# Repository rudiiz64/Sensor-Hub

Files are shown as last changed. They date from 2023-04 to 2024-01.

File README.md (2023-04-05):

# Sensor-Hub

__Purpose:__ The purpose of this design is to start with an idea and see it to completion. Realistically, this sensor hub serves no real purpose, as it is mainly a way for me to begin initial schematic design and layout. This design tackles a multitude of areas that needed to be practiced, such as component selection, power distribution, and further acquiring data from datasheets.

This system utilizes an STM32L100 chip with an active reset and boot mode toggle, USB-B receptacle, onboard sensors, which include light intensity, humiditiy, and ambient temperature, an SD card, SWD breakout pins, a +5V to +3.3V linear voltage regulator, a screw terminal to fit a +5V battery with a protective eFuse, and a battery recharge circuit.

__Lessons learned:__ One of the most valuable lessons learned while progressing through this project is to fully understand what the system needs and whether or not those needs can be met. This means providing proper current, minimizing voltage drop due to trace length/width, and also understanding return current. Another notable lesson is that sometimes designs can be a little weird due to component placement. From my experience, the initial component placement will not result in the greatest system, as my original design had a voltage drop of 0.4V in the 3.3V line due to excessive trace lengths. Lastly, I learned that more time needs to be spent on designing the power side in terms of component selection AND feasibility. For instance, the design was originally only USB powered, which made no real sense as these kinds of sensors need to be flexible in terms of placement. Because of this reasoning, a battery was implemented with a battery recharge and a protective eFuse.

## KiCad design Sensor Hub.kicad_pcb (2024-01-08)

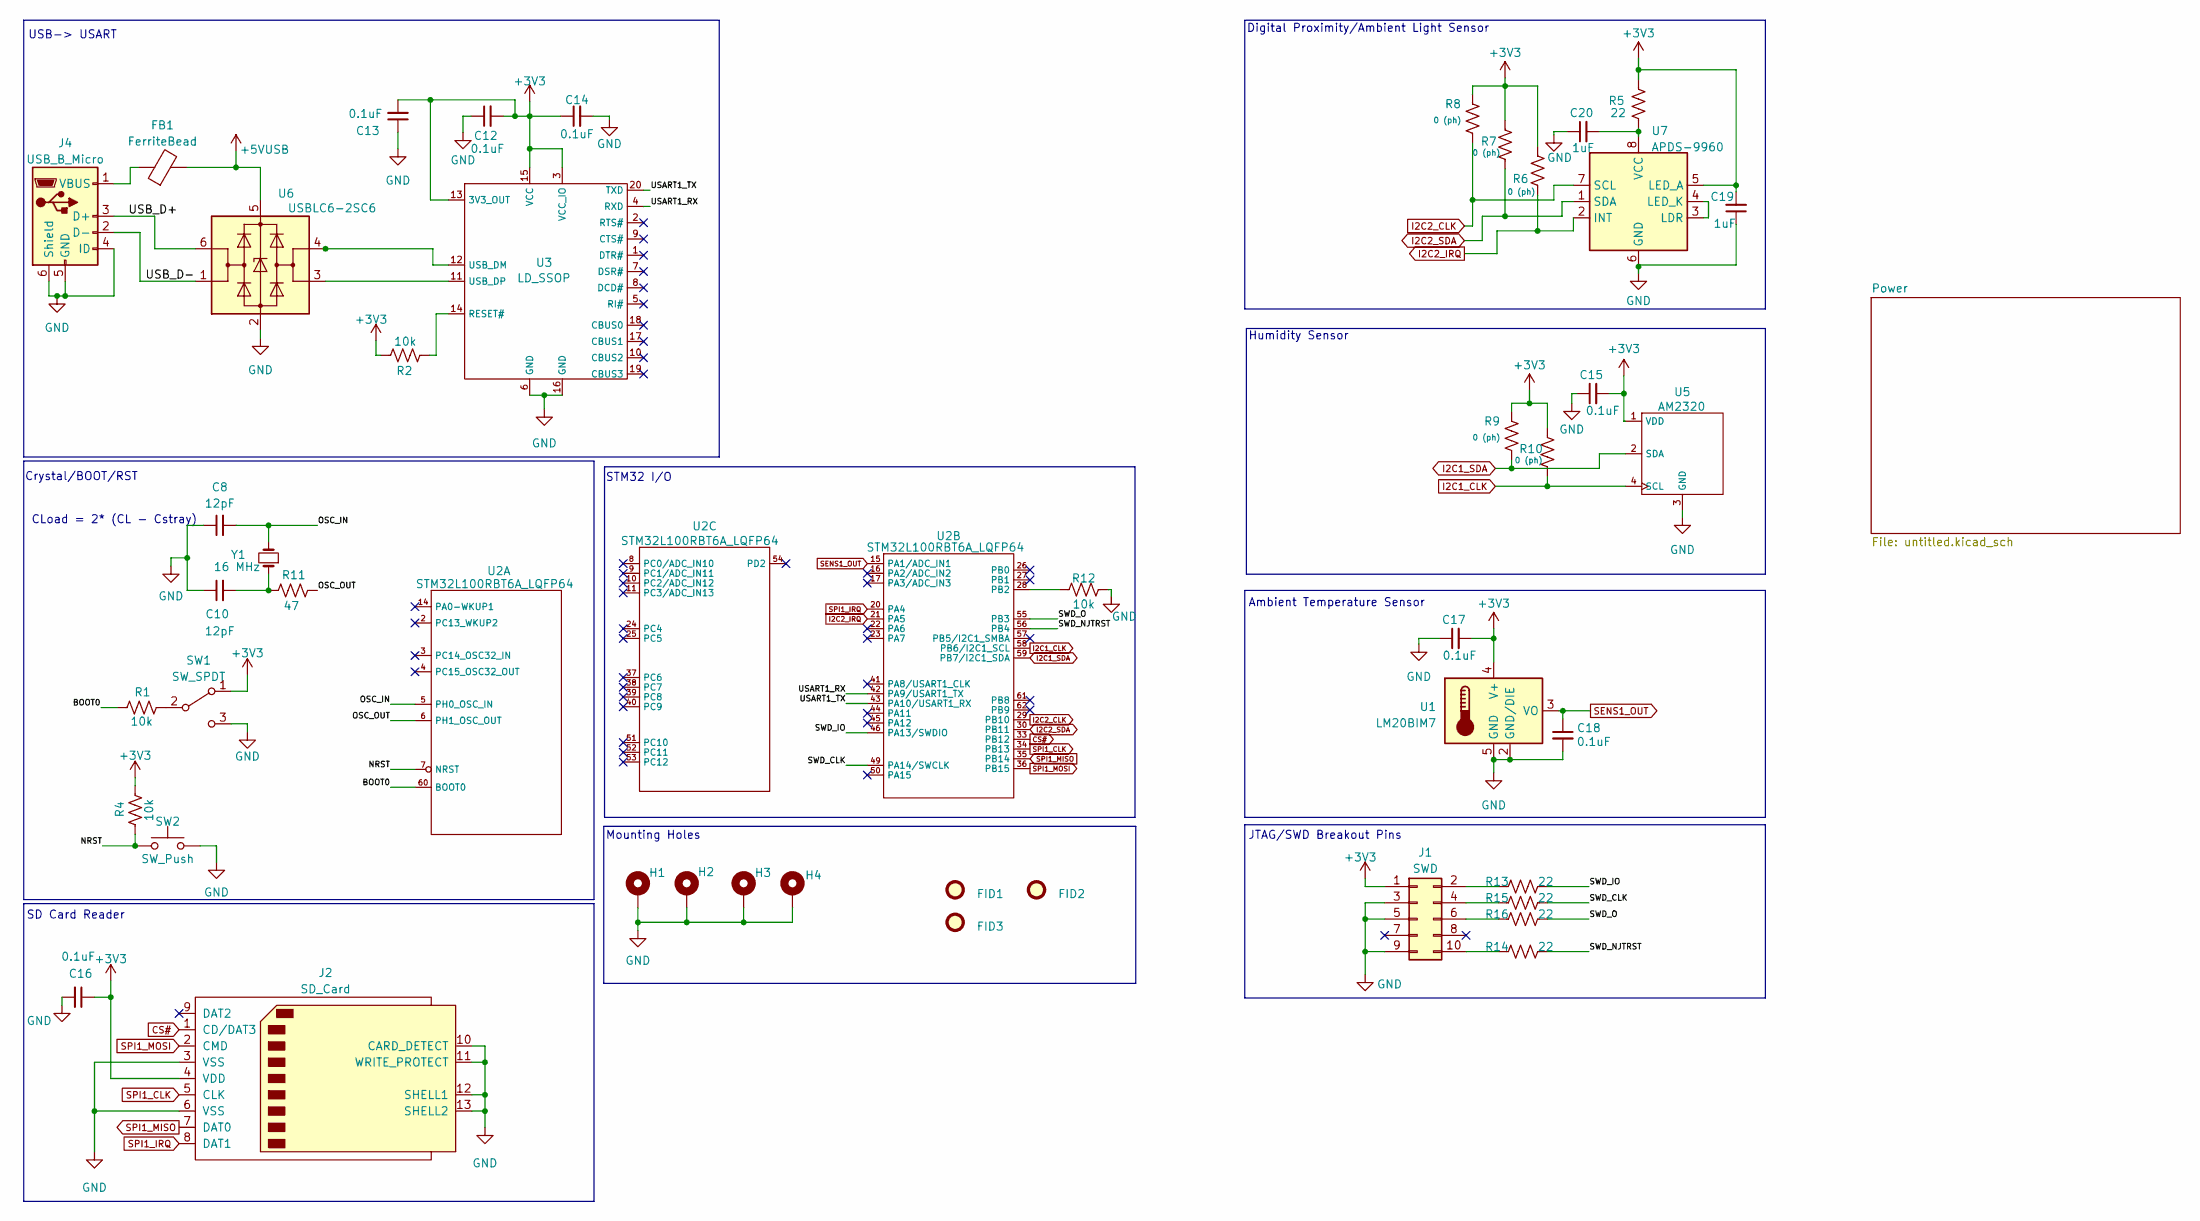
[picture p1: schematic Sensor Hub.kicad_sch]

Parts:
C8, C10: 12pF; C_0402_1005Metric
C12, C13, C14, C15, C16, C17, C18: 0.1uF; C_0603_1608Metric
C19, C20: 1uF; C_0603_1608Metric
FB1: FerriteBead; LairdTech_28C0236-0JW-10
FID1, FID2, FID3: Fiducial; Fiducial_1mm_Mask2mm
H1, H2, H3, H4: MountingHole_Pad; MountingHole_2.2mm_M2_Pad_Via
J1: SWD; PinHeader_2x05_P2.00mm_Vertical
J2: SD_Card; SD_Hirose_DM1AA_SF_PEJ82
J4: USB_B_Micro; USB_Micro-B_Amphenol_10118194_Horizontal
R1, R2, R4, R12: 10k; R_0402_1005Metric
R5, R13, R14, R15, R16: 22; R_0402_1005Metric
R6, R7, R8, R9, R10: 0 (ph); R_0402_1005Metric
R11: 47; R_0402_1005Metric
SW1: SW_SPDT; SW_E-Switch_EG1271_SPDT
SW2: SW_Push; SW_PUSH_6mm
U1: LM20BIM7; SOT-353_SC-70-5
U2: STM32L100RBT6A_LQFP64
U3: LD_SSOP; FT231_20_LD_SSOP
U5: AM2320; PinSocket_1x04_P2.00mm_Vertical
U6: USBLC6-2SC6; SOT-23-6
U7: APDS-9960; Avago_APDS-9960
Y1: 16 MHz; Crystal_SMD_0603-2Pin_6.0x3.5mm

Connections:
+3V3: C12.2, C13.2, C14.1, C15.2, C16.1, C17.2, C19.2, J1.1, J2.4 (VDD), R2.1, R4.1, R5.2, R6.2, R7.2, R8.2, R9.2, R10.2, SW1.1 (A), U1.4 (V+), U3.3 (VCC_IO), U3.13 (3V3_OUT), U3.15 (VCC), U5.1 (VDD), U7.5 (LED_A); also elsewhere on the board
+5V: FB1.2, U6.5 (VBUS); also elsewhere on the board
/BOOT0: R1.2, U2.60 (BOOT0)
/NRST: R4.2, SW2.1, U2.7 (NRST)
/OSC_IN: C8.2, U2.5 (PH0_OSC_IN), Y1.2
/OSC_OUT: R11.1, U2.6 (PH1_OSC_OUT)
/SWD_CLK: R15.2, U2.49 (PA14/SWCLK)
/SWD_IO: R13.1, U2.46 (PA13/SWDIO)
/SWD_NJTRST: R14.2, U2.56 (PB4)
/SWD_O: R16.2, U2.55 (PB3)
/USART1_RX: U2.42 (PA9/USART1_TX), U3.4 (RXD)
/USART1_TX: U2.43 (PA10/USART1_RX), U3.20 (TXD)
/USB_D+: J4.3 (D+), U6.6 (I/O1)
/USB_D-: J4.2 (D-), U6.1 (I/O1)
CS#: J2.1 (CD/DAT3), U2.33 (PB12)
GND: C8.1, C10.1, C12.1, C13.1, C14.2, C15.1, C16.2, C17.1, C18.2, C19.1, C20.1, H1.1, H2.1, H3.1, H4.1, J1.3, J1.5, J1.9, J2.3 (VSS), J2.6 (VSS), J2.10 (CARD_DETECT), J2.11 (WRITE_PROTECT), J2.12 (SHELL1), J2.13 (SHELL2), J2.CP, J2.SH, J2.SW, J2.WP, J4.4 (ID), J4.5 (GND), J4.6 (Shield), R12.2, SW1.3 (C), SW2.2, U1.2 (GND/DIE), U1.5 (GND), U3.6 (GND), U3.16 (GND), U5.3 (GND), U6.2 (GND), U7.6 (GND); also elsewhere on the board
I2C1_CLK: R10.1, U2.58 (PB6/I2C1_SCL), U5.4 (SCL)
I2C1_SDA: R9.1, U2.59 (PB7/I2C1_SDA), U5.2 (SDA)
I2C2_CLK: R8.1, U2.29 (PB10), U7.7 (SCL)
I2C2_IRQ: R6.1, U2.21 (PA5), U7.2 (INT)
I2C2_SDA: R7.1, U2.30 (PB11), U7.1 (SDA)
unnamed: C10.2, R11.2, Y1.1
unnamed: J1.2, R13.2
unnamed: J1.4, R15.1
unnamed: J1.6, R16.1
unnamed: J1.10, R14.1
unnamed: FB1.1, J4.1 (VBUS)
unnamed: R1.1, SW1.2 (B)
unnamed: R12.1, U2.28 (PB2)
unnamed: R2.2, U3.14 (RESET#)
unnamed: U3.12 (USB_DM), U6.4 (I/O2)
unnamed: U3.11 (USB_DP), U6.3 (I/O2)
unnamed: U7.3 (LDR), U7.4 (LED_K)
unnamed: C20.2, R5.1, U7.8 (VCC)
SENS1_OUT: C18.1, U1.3 (VO), U2.15 (PA1/ADC_IN1)
SPI1_CLK: J2.5 (CLK), U2.34 (PB13)
SPI1_IRQ: J2.8 (DAT1), U2.20 (PA4)
SPI1_MISO: J2.7 (DAT0), U2.35 (PB14)
SPI1_MOSI: J2.2 (CMD), U2.36 (PB15)

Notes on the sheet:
STM32 I/O
Crystal/BOOT/RST
CLoad = 2* (CL - Cstray)
Mounting Holes
Ambient Temperature Sensor
Digital Proximity/Ambient Light Sensor
JTAG/SWD Breakout Pins
SD Card Reader
Humidity Sensor
USB-> USART

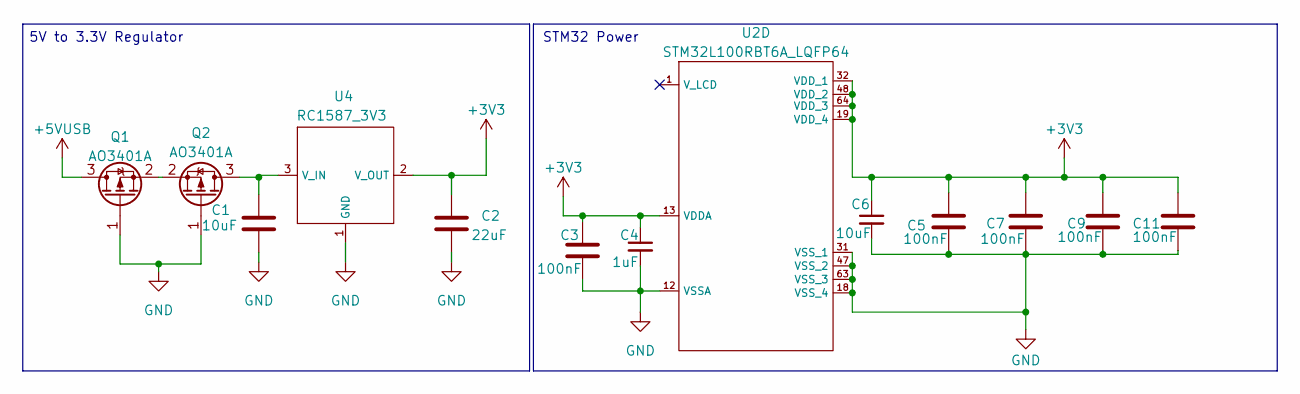
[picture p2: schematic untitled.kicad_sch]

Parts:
C1, C6: 10uF; C_0603_1608Metric
C2: 22uF; C_0603_1608Metric
C3, C5, C7, C9, C11: 100nF; C_0402_1005Metric
C4: 1uF; C_0603_1608Metric
Q1, Q2: AO3401A; SOT-23
U2: STM32L100RBT6A_LQFP64
U4: RC1587_3V3; RC1587M3V3T

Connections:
+3V3: C2.1, C3.1, C4.1, C5.1, C6.1, C7.1, C9.1, C11.1, U2.13 (VDDA), U2.19 (VDD_4), U2.32 (VDD_1), U2.48 (VDD_2), U2.64 (VDD_3), U4.2 (V_OUT); also elsewhere on the board
+5V: Q1.3 (D); also elsewhere on the board
GND: C1.2, C2.2, C3.2, C4.2, C5.2, C6.2, C7.2, C9.2, C11.2, Q1.1 (G), Q2.1 (G), U2.12 (VSSA), U2.18 (VSS_4), U2.31 (VSS_1), U2.47 (VSS_2), U2.63 (VSS_3), U4.1 (GND); also elsewhere on the board
unnamed: Q1.2 (S), Q2.2 (S)
unnamed: C1.1, Q2.3 (D), U4.3 (V_IN)

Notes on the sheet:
STM32 Power
5V to 3.3V Regulator

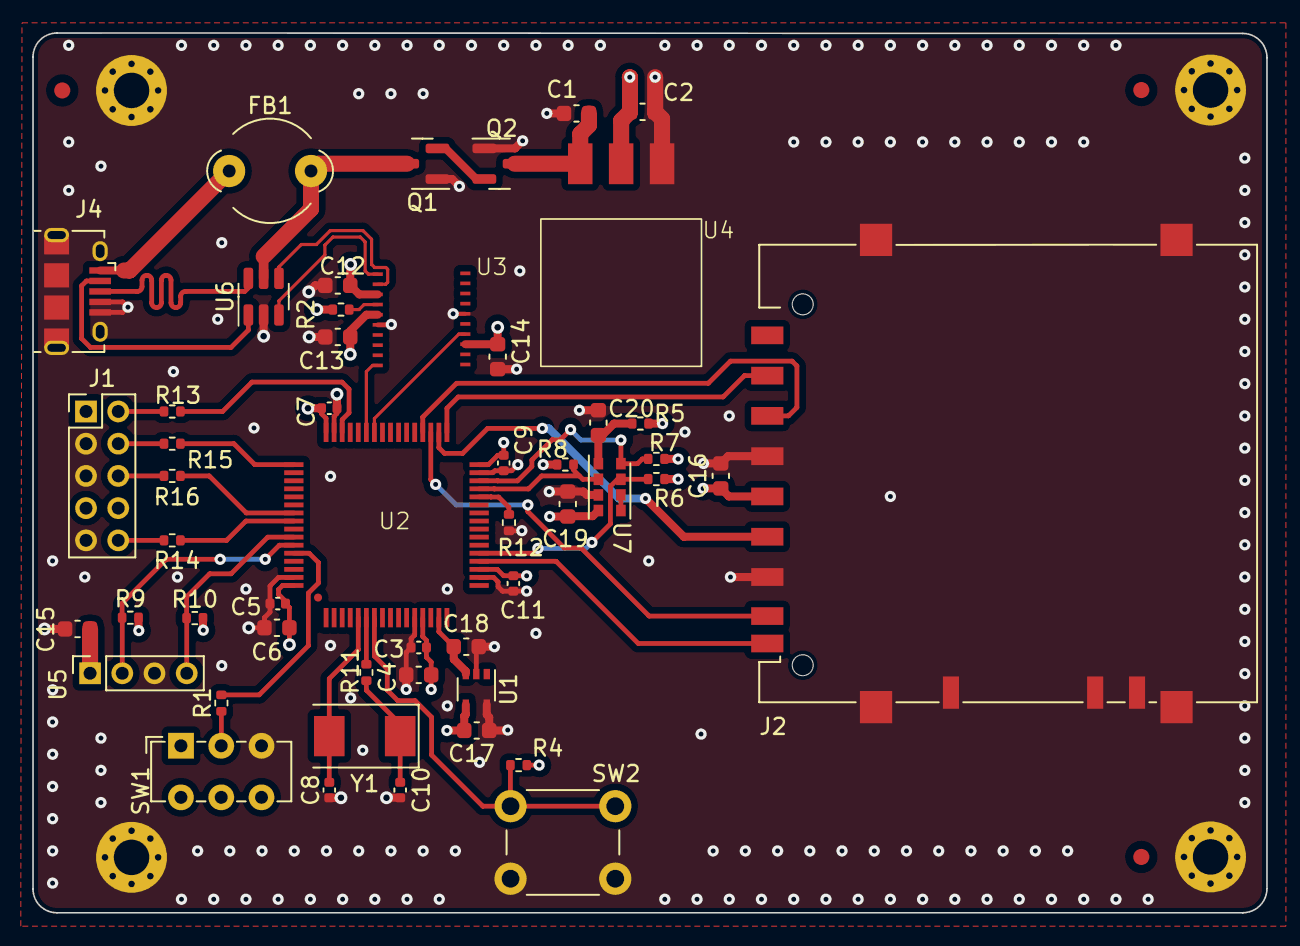
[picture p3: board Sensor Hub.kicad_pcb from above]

Board: 4 copper layers, 76.6 x 54.6 mm, 58 parts (0 on the bottom side), 41 nets.

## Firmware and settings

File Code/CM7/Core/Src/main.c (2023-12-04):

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
/* Includes ------------------------------------------------------------------*/
#include "main.h"
#include "string.h"

/* USER CODE BEGIN Includes */
#include <stdio.h>
#include "bmp180.h"
/* USER CODE END Includes */

/* USER CODE BEGIN PD */

#ifndef HSEM_ID_0
#define HSEM_ID_0 (0U) /* HW semaphore 0*/
#endif

/* USER CODE END PD */

#if defined ( __ICCARM__ ) /*!< IAR Compiler */
#pragma location=0x30000000
ETH_DMADescTypeDef  DMARxDscrTab[ETH_RX_DESC_CNT]; /* Ethernet Rx DMA Descriptors */
#pragma location=0x30000200
ETH_DMADescTypeDef  DMATxDscrTab[ETH_TX_DESC_CNT]; /* Ethernet Tx DMA Descriptors */

#elif defined ( __CC_ARM )  /* MDK ARM Compiler */

__attribute__((at(0x30000000))) ETH_DMADescTypeDef  DMARxDscrTab[ETH_RX_DESC_CNT]; /* Ethernet Rx DMA Descriptors */
__attribute__((at(0x30000200))) ETH_DMADescTypeDef  DMATxDscrTab[ETH_TX_DESC_CNT]; /* Ethernet Tx DMA Descriptors */

#elif defined ( __GNUC__ ) /* GNU Compiler */
ETH_DMADescTypeDef DMARxDscrTab[ETH_RX_DESC_CNT] __attribute__((section(".RxDecripSection"))); /* Ethernet Rx DMA Descriptors */
ETH_DMADescTypeDef DMATxDscrTab[ETH_TX_DESC_CNT] __attribute__((section(".TxDecripSection")));   /* Ethernet Tx DMA Descriptors */

#endif

ETH_TxPacketConfig TxConfig;

ETH_HandleTypeDef heth;

I2C_HandleTypeDef hi2c1;

TIM_HandleTypeDef htim16;

UART_HandleTypeDef huart3;

PCD_HandleTypeDef hpcd_USB_OTG_FS;

/* USER CODE BEGIN PV */
  //static const uint8_t BMP180_ADDRS = BMP180_ADDR << 1;

/* USER CODE END PV */

void SystemClock_Config(void);
static void MX_GPIO_Init(void);
static void MX_ETH_Init(void);
static void MX_USART3_UART_Init(void);
static void MX_USB_OTG_FS_PCD_Init(void);
static void MX_TIM16_Init(void);
static void MX_I2C1_Init(void);
/**
  * @brief  The application entry point.
  * @retval int
  */
int main(void)
{
/* USER CODE BEGIN Boot_Mode_Sequence_0 */
  int32_t timeout;
/* USER CODE END Boot_Mode_Sequence_0 */

/* USER CODE BEGIN Boot_Mode_Sequence_1 */
  /* Wait until CPU2 boots and enters in stop mode or timeout*/
  timeout = 0xFFFF;
  while((__HAL_RCC_GET_FLAG(RCC_FLAG_D2CKRDY) != RESET) && (timeout-- > 0));
  if ( timeout < 0 )
  {
  Error_Handler();
  }
/* USER CODE END Boot_Mode_Sequence_1 */
  /* MCU Configuration--------------------------------------------------------*/

  /* Reset of all peripherals, Initializes the Flash interface and the Systick. */
  HAL_Init();

  /* Configure the system clock */
  SystemClock_Config();
/* USER CODE BEGIN Boot_Mode_Sequence_2 */
/* When system initialization is finished, Cortex-M7 will release Cortex-M4 by means of
HSEM notification */
/*HW semaphore Clock enable*/
__HAL_RCC_HSEM_CLK_ENABLE();
/*Take HSEM */
HAL_HSEM_FastTake(HSEM_ID_0);
/*Release HSEM in order to notify the CPU2(CM4)*/
HAL_HSEM_Release(HSEM_ID_0,0);
/* wait until CPU2 wakes up from stop mode */
timeout = 0xFFFF;
while((__HAL_RCC_GET_FLAG(RCC_FLAG_D2CKRDY) == RESET) && (timeout-- > 0));
if ( timeout < 0 )
{
Error_Handler();
}
/* USER CODE END Boot_Mode_Sequence_2 */

  /* Initialize all configured peripherals */
  MX_GPIO_Init();
  MX_ETH_Init();
  MX_USART3_UART_Init();
  MX_USB_OTG_FS_PCD_Init();
  MX_TIM16_Init();
  MX_I2C1_Init();
  /* USER CODE BEGIN 2 */

  // Start Timer
  HAL_TIM_Base_Start_IT(&htim16);
  /* USER CODE END 2 */

  /* Infinite loop */
  /* USER CODE BEGIN WHILE */
  while (1)
  {
	  // Tell BMP180 we want to read from the temp reg
//	  buf[0] = REG_TEMP;
//	  ret = HAL_I2C_Master_Transmit(&hi2c1, BMP180_ADDR, buf, 1, HAL_MAX_DELAY);
//	  if (ret != HAL_OK){
//		  strcpy((char*) buf, "Error TX\r\n");
//	  }
//	  else {
//		  //Combine the bytes
//		  val = ((int16_t) buf[0] << 4 | buf[1] >> 4);
//	  }
//	  strcpy((char*) buf, "Hello!\r\n");
//	  HAL_UART_Transmit(&huart3, buf, strlen((char*) buf), HAL_MAX_DELAY);
//	  HAL_Delay(500);

    /* USER CODE END WHILE */

    /* USER CODE BEGIN 3 */
  }
  /* USER CODE END 3 */
}

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
/* USER CODE BEGIN 4 */
// Callback function: Timer has reset
void HAL_TIM_PeriodElapsedCallback(TIM_HandleTypeDef *htim){
	if (htim == &htim16){
		HAL_GPIO_TogglePin(LD1_GPIO_Port, LD1_Pin);
	}
}
/* USER CODE END 4 */
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


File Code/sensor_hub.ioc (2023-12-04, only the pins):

Mcu.UserName=STM32H745ZITx
PA1.Signal=ETH_REF_CLK
PA11.Signal=USB_OTG_FS_DM
PA12.Signal=USB_OTG_FS_DP
PA2.Signal=ETH_MDIO
PA7.Signal=ETH_CRS_DV
PA8.Signal=USB_OTG_FS_SOF
PA9.Signal=USB_OTG_FS_VBUS
PB0.GPIO_Label=LD1 [Green Led]
PB0.Signal=GPIO_Output
PB13.Signal=ETH_TXD1
PB14.GPIO_Label=LD3 [Red Led]
PB14.Signal=GPIO_Output
PB6.Signal=I2C1_SCL
PB7.Signal=I2C1_SDA
PC1.Signal=ETH_MDC
PC13.GPIO_Label=B1 [Blue PushButton]
PC13.Signal=GPIO_Input
PC4.Signal=ETH_RXD0
PC5.Signal=ETH_RXD1
PD10.GPIO_Label=USB_OTG_FS_PWR_EN
PD10.Signal=GPIO_Output
PD8.GPIO_Label=STLINK_RX
PD8.Signal=USART3_TX
PD9.GPIO_Label=STLINK_TX
PD9.Signal=USART3_RX
PE1.GPIO_Label=LD2 [Yellow Led]
PE1.Signal=GPIO_Output
PG11.Signal=ETH_TX_EN
PG13.Signal=ETH_TXD0
PG7.GPIO_Label=USB_OTG_FS_OVCR
PG7.Signal=GPXTI7

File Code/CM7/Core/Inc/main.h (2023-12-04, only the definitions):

#define LD1_Pin GPIO_PIN_0
#define LD1_GPIO_Port GPIOB
#define LD3_Pin GPIO_PIN_14
#define LD3_GPIO_Port GPIOB
#define STLINK_RX_Pin GPIO_PIN_8
#define STLINK_RX_GPIO_Port GPIOD
#define STLINK_TX_Pin GPIO_PIN_9
#define STLINK_TX_GPIO_Port GPIOD

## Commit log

2023-03-12 Initial push
    Rev 0.1
    - Initial schematic
    [Sensor Hub.kicad_pcb, Sensor Hub.kicad_sch, untitled.kicad_sch]
2023-03-12 Update to schem
    - Updated per Adi's feedback
    [Sensor Hub.kicad_sch, untitled.kicad_sch]
2023-03-13 Updated Schematic
    - Added LTC4002 battery management IC
    - Updated previous ICs to reflect given feedback
    [Sensor Hub.kicad_sch, untitled.kicad_sch]
2023-03-20 Rev 0.3
    + Updated schematic to reflect utilization of USB-B micro instead of USB-C
    + Began initial layout of PCB
    - Need to look into eFuse layout, as specified layout recommendation utilizes ground pours
    - Need to update SD Card footprint as pads are not linked
    [Sensor Hub.kicad_pcb, Sensor Hub.kicad_sch, untitled.kicad_sch]
2023-03-29 Rev 1.0
    + Initial PCB board completed
    [Sensor Hub.kicad_pcb, Sensor Hub.kicad_sch]
2023-04-03 Updated to Rev 1.1
    + Adjusted trace widths to appropriately fit IC pads while supporting wanted current and minimizing vdrop
    + Adjusted edge cuts of PCB to remove unnecessary areas
    [Sensor Hub.kicad_pcb, Sensor Hub.kicad_sch, untitled.kicad_sch]
2023-09-21 Updated Rev 2.0
    + Revamped board to 4 layer with components on both signal layers (top/bottom)
    + Adjusted compactness of components, reducing size by approx 30%
    + Added mounting holes for mounting purposes
    - Removed battery, batt charger, eFuse (USB driven only)
    [Sensor Hub.kicad_pcb, Sensor Hub.kicad_sch, untitled.kicad_sch]
2023-12-04 Rev 0.1 Code
    + Added initial code for BMP180 (I2C) on STM32Cube
2024-01-08 Updated to Rev B
    + Added ESD protection on USB side
    + Redesigned board layout to a SIG/GND/GND/SIG stack up and using L4 as 3V3 plane
    + Resized capacitors and resistors to 0402
    + Added 3D models of certain components
    + Added ferrite bead to 5V line
    [Sensor Hub.kicad_pcb, Sensor Hub.kicad_sch, untitled.kicad_sch]

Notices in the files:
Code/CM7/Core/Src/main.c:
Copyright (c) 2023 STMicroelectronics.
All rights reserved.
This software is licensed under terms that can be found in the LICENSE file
